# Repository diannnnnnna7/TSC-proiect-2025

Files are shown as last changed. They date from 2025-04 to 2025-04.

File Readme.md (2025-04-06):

E-Book Reader cu e-Paper si ESP32-C6

DeskAssistant este un dispozitiv portabil de tip E-Book Reader, construit in jurul microcontrolerului ESP32-C6, cu consum redus de energie si capabilitati de conectivitate Wi-Fi. Dispozitivul utilizeaza un display e-paper pentru citirea confortabila a cartilor, fiind alimentat de la o baterie Li-Po si gandit sa functioneze autonom timp indelungat.

Componente principale:

ESP32-C6 – Microcontroler principal cu Wi-Fi, SPI si I2C

E-Paper Display – Afisaj principal, ideal pentru citirea fara oboseala a ochilor

Memorie Flash NOR 64MB – Spatiu generos pentru carti, configurari sau fisiere

Senzor ambiental BME688 – Masoara temperatura, presiunea, umiditatea si calitatea aerului

RTC DS3231 – Ceas de timp real cu precizie ridicata si consum scazut

SD Card Slot – Optiune de stocare suplimentara pentru fisiere EPUB/PDF

Fuel Gauge MAX17048 – Monitorizeaza in timp real nivelul bateriei

LDO Regulator – Asigura tensiunea de 3.3V stabila pentru toate componentele

Conector USB-C – Incarcare si comunicatie UART pentru debugging

Dispozitivul se alimenteaza de la o baterie Li-Po si poate fi incarcat prin portul USB-C, avand un circuit de incarcare dedicat (MCP73831).

Interfete de comunicatie:

SPI – Utilizat pentru E-Paper, memorie Flash si card SD

I2C – Utilizat pentru senzorul BME688, RTC si Fuel Gauge

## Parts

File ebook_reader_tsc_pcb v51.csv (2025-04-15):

Qty | Value | Device | Package | Parts | Description | ARROW_PART_NUMBER | ARROW_PRICE-STOCK | AVAILABILITY | CENTROID_NOT_SPECIFIED | CHECK_PRICES | COPYRIGHT | DATASHEET | DESCRIPTION | DIGIKEY_DESCRIPTION | DIGIKEY_PART_NUMBER | HEIGHT | LEAD_FREE | MANUFACTURER_NAME | MANUFACTURER_PART_NUMBER | MF | MFR_NAME | MOUSER_PART_NUMBER | MOUSER_PRICE-STOCK | MOUSER_TESTING_PART_NUMBER | MOUSER_TESTING_PRICE-STOCK | MP | MPN | PACKAGE | POPULARITY | PREFIX | PRICE | PROD_ID | PURCHASE-URL | ROHS | SNAPEDA_LINK | SPICEMODEL | SPICEPREFIX | TEMPERATURE_RANGE_HIGH | TEMPERATURE_RANGE_LOW | TP_SIGNAL_NAME | VALUE
1 |  | ADAFRUIT_LEDCHIP-LED0603 | ADAFRUIT_CHIP-LED0603 | CHG_LED | LED
1 |  | SJ | SJ | SJ1 | SMD solder JUMPER |  |  |  |  |  |  |  |  |  |  |  |  |  |  |  |  |  |  |  |  |  |  |  | 3
1 | 0.47 | ESP32_WROVER_EAGLE-LTSPICE_RR0402 | ESP32_WROVER_EAGLE-LTSPICE_R0402 | R3 | RESISTOR, European symbol |  |  |  |  |  |  |  |  |  |  |  |  |  |  |  |  |  |  |  |  |  |  |  |  |  |  |  |  |  |  | NONE | R
1 | 100k | ESP32_WROVER_EAGLE-LTSPICE_RR0402 | ESP32_WROVER_EAGLE-LTSPICE_R0402 | R1_PWRUSB | RESISTOR, European symbol |  |  |  |  |  |  |  |  |  |  |  |  |  |  |  |  |  |  |  |  |  |  |  |  |  |  |  |  |  |  | NONE | R
8 | 100nF | ESP32_WROVER_EAGLE-LTSPICE_CC0402 | ESP32_WROVER_EAGLE-LTSPICE_C0402 | C1, C2, C4_USB, C6, C8, C9, C10, C_DELAY | CAPACITOR, European symbol |  |  |  |  |  |  |  |  |  |  |  |  |  |  |  |  |  |  |  |  |  |  |  |  |  |  |  |  |  |  | NONE | C
1 | 100uF | RCL_CPOL-EUCT3528 | RCL_CT3528 | C3 | POLARIZED CAPACITOR, European symbol |  |  |  |  |  |  |  |  |  |  |  |  |  |  |  |  |  |  |  |  |  |  |  | 0 |  |  |  |  |  |  |  | C
16 | 10K | ESP32_WROVER_EAGLE-LTSPICE_RR0402 | ESP32_WROVER_EAGLE-LTSPICE_R0402 | R1, R1_PINH, R1_PINH1, R2-PINH, R2_PINH1, R4, R5, R6, R7, R8, R9, R10, R_BOOT, R_CHANGE, R_CL1, R_RESET | RESISTOR, European symbol |  |  |  |  |  |  |  |  |  |  |  |  |  |  |  |  |  |  |  |  |  |  |  |  |  |  |  |  |  |  | NONE | R
1 | 10uF | ESP32_WROVER_EAGLE-LTSPICE_CC0402 | ESP32_WROVER_EAGLE-LTSPICE_C0402 | C7 | CAPACITOR, European symbol |  |  |  |  |  |  |  |  |  |  |  |  |  |  |  |  |  |  |  |  |  |  |  |  |  |  |  |  |  |  | NONE | C
1 | 112A-TAAR-R03_ATTEND | 112A-TAAR-R03_ATTEND | 112ATAARR03ATTEND | J4 | Micro SD Card Socket, Push-Push Type, Top Mount, SMT, H=1.83mm, 10u |  |  |  |  |  |  |  | Micro SD Card Socket | Push-Push Type | Top Mount | SMT | H=1.83mm | 10u |  |  | 1.9mm |  | ATTEND | 112A-TAAR-R03 ATTEND
1 | 15 | ESP32_WROVER_EAGLE-LTSPICE_RR0402 | ESP32_WROVER_EAGLE-LTSPICE_R0402 | R_CAPACITOR | RESISTOR, European symbol |  |  |  |  |  |  |  |  |  |  |  |  |  |  |  |  |  |  |  |  |  |  |  |  |  |  |  |  |  |  | NONE | R
1 | 1uF | ESP32_WROVER_EAGLE-LTSPICE_CC0402 | ESP32_WROVER_EAGLE-LTSPICE_C0402 | C5 | CAPACITOR, European symbol |  |  |  |  |  |  |  |  |  |  |  |  |  |  |  |  |  |  |  |  |  |  |  |  |  |  |  |  |  |  | NONE | C
10 | 1uF/50V | ESP32_WROVER_EAGLE-LTSPICE_CC0402 | ESP32_WROVER_EAGLE-LTSPICE_C0402 | EPD_C1, EPD_C2, EPD_C5, EPD_C6, EPD_C7, EPD_C8, EPD_C9, EPD_C10, EPD_C11, EPD_C12 | CAPACITOR, European symbol |  |  |  |  |  |  |  |  |  |  |  |  |  |  |  |  |  |  |  |  |  |  |  |  |  |  |  |  |  |  | NONE | C
1 | 2.2 | ESP32_WROVER_EAGLE-LTSPICE_RR0402 | ESP32_WROVER_EAGLE-LTSPICE_R0402 | R2 | RESISTOR, European symbol |  |  |  |  |  |  |  |  |  |  |  |  |  |  |  |  |  |  |  |  |  |  |  |  |  |  |  |  |  |  | NONE | R
1 | 200 | ESP32_WROVER_EAGLE-LTSPICE_RR0402 | ESP32_WROVER_EAGLE-LTSPICE_R0402 | R1_BAT | RESISTOR, European symbol |  |  |  |  |  |  |  |  |  |  |  |  |  |  |  |  |  |  |  |  |  |  |  |  |  |  |  |  |  |  | NONE | R
2 | 20V/4.2A/52m?/1.4W | ESP32_WROVER_SPARKFUN-DISCRETESEMI_MOSFET_PCH-DMG2305UX-7 | ESP32_WROVER_SPARKFUN-DISCRETESEMI_SOT23-3 | Q1, Q2 | P-channel MOSFETs |  |  |  |  |  |  |  |  |  |  |  |  |  |  |  |  |  |  |  |  |  |  |  |  |  |  | TRAN-14388 |  |  |  |  |  |  |  |  | 20V/4.2A/52m?/1.4W
1 | 2K | ESP32_WROVER_EAGLE-LTSPICE_RR0402 | ESP32_WROVER_EAGLE-LTSPICE_R0402 | R2_BAT | RESISTOR, European symbol |  |  |  |  |  |  |  |  |  |  |  |  |  |  |  |  |  |  |  |  |  |  |  |  |  |  |  |  |  |  | NONE | R
5 | 4.7uF | ESP32_WROVER_EAGLE-LTSPICE_CC0402 | ESP32_WROVER_EAGLE-LTSPICE_C0402 | C1_BAT, C1_BAT1, C1_BAT2, C2_BAT, C5_USB | CAPACITOR, European symbol |  |  |  |  |  |  |  |  |  |  |  |  |  |  |  |  |  |  |  |  |  |  |  |  |  |  |  |  |  |  | NONE | C
1 | 4.7uF/25V | ESP32_WROVER_EAGLE-LTSPICE_CC0402 | ESP32_WROVER_EAGLE-LTSPICE_C0402 | C4 | CAPACITOR, European symbol |  |  |  |  |  |  |  |  |  |  |  |  |  |  |  |  |  |  |  |  |  |  |  |  |  |  |  |  |  |  | NONE | C
2 | 5k1 | ESP32_WROVER_EAGLE-LTSPICE_RR0402 | ESP32_WROVER_EAGLE-LTSPICE_R0402 | R2-USB, R2-USB1 | RESISTOR, European symbol |  |  |  |  |  |  |  |  |  |  |  |  |  |  |  |  |  |  |  |  |  |  |  |  |  |  |  |  |  |  | NONE | R
1 | 68uH | 744043680IND_4828-WE-TPC_WRE | IND_4828-WE-TPC_WRE | L1 |  |  |  |  |  |  | Copyright (C) 2024 Ultra Librarian. All rights reserved. |  |  |  |  |  |  |  | 744043680 |  | Wurth Electronics
1 | BD5229G-TR | BD5229G-TR | SOT95P280X125-5N | IC1 | Voltage Detector with Adjustable Delay Time: CMOS processes are utilized to develop high precision, low current consumption CMOS reset ICs that allow arbitrary setting of the delay time. The extensive lineup includes both Nch Open Drain and CMOS output types in a wide range of detection voltages (from 2.3V to 6.0V, in 0.1V steps), enabling selection of the ideal solution based on customer requirements. In addition, the entire series is of course both lead-free and RoHS-compliant. |  |  |  |  |  |  |  | Voltage Detector with Adjustable Delay Time: CMOS processes are utilized to develop high precision | low current consumption CMOS reset ICs that allow arbitrary setting of the delay time. The extensive lineup includes both Nch Open Drain and CMOS output types in a wide range of detection voltages (from 2.3V to 6.0V | in 0.1V steps) | enabling selection of the ideal solution based on customer requirements. In addition | the entire series is of course both lead-free and RoHS-compliant. |  |  | 1.25mm |  | ROHM Semiconductor | BD5229G-TR |  |  | 755-BD5229G-TR | https://www.mouser.co.uk/ProductDetail/ROHM-Semiconductor/BD5229G-TR?qs=4kLU8WoGk0vvnhrrYwdszw%3D%3D
3 | BUTTON_CUSYOMV1 | BUTTON_CUSYOMV1 | MYBUTTON | BOOT_BUTTON, CHANGE_BUTTON, RESET_BUTTON
1 | CPH3225A | CPH3225A | CAPCP3225X100N | C10_SUPERCAP | Cap 0.011F 3.3V 1210 Flat Check availability |  |  | Not in stock |  | https://www.snapeda.com/parts/CPH3225A/Seiko+Instruments/view-part/?ref=eda |  |  | 11 mF (EDLC) Supercapacitor 3.3 V 1210 (3225 Metric) - - |  |  |  |  |  |  | Seiko Instruments |  |  |  |  |  | CPH3225A |  | 1210 Seiko |  |  | None |  | https://www.snapeda.com/api/url_track_click_mouser/?unipart_id=562593&manufacturer=Seiko Instruments&part_name=CPH3225A&search_term=None |  | https://www.snapeda.com/parts/CPH3225A/Seiko+Instruments/view-part/?ref=snap
1 | DS3231SN# | DS3231SN# | SOIC127P1032X265-16N | U3 | Real Time Clock Serial 16-Pin SOIC W T/R Check availability |  |  | In Stock |  | https://www.snapeda.com/parts/DS3231SN%23/Analog+Devices/view-part/?ref=eda |  |  | Extremely Accurate I2C-Integrated RTC/TCXO/Crystal |  |  |  |  |  |  | Analog Devices |  |  |  |  |  | DS3231SN# |  | SOIC-16 Maxim |  |  | None |  | https://www.snapeda.com/api/url_track_click_mouser/?unipart_id=99048&manufacturer=Analog Devices&part_name=DS3231SN#&search_term=None |  | https://www.snapeda.com/parts/DS3231SN%23/Analog+Devices/view-part/?ref=snap
1 | ESP32-C6-WROOM-1-N8 | ESP32-C6-WROOM-1-N8 | XCVR_ESP32-C6-WROOM-1-N8 | U2 | Check availability |  |  | In Stock |  | https://www.snapeda.com/parts/ESP32-C6-WROOM-1-N8/Espressif+Systems/view-part/?ref=eda |  |  | Multiprotocol Modules ESP32-C6 module | Wi-Fi 6 in 2.4 GHz band | Bluetooth 5 | Zigbee 3.0 and Thread. ESP34-WROOM Compatible - ENGINEERING SAMPLE |  |  |  |  |  |  | Espressif Systems |  |  |  |  |  | ESP32-C6-WROOM-1-N8 |  | None |  |  | None |  |  |  | https://www.snapeda.com/parts/ESP32-C6-WROOM-1-N8/Espressif+Systems/view-part/?ref=snap
1 | ESP32C6_VARISTORCN1812 | ESP32C6_VARISTORCN1812 | ESP32C6_VARISTOR_CT/CN1812 | PFMF.050.1 | VARISTOR |  |  |  |  |  |  |  |  |  |  |  |  |  |  |  |  |  |  |  |  |  |  |  | 0
2 | ESP32_WROVER_AVX---SD0805S020S1R0_AVX_SD0805S020S1R0_0_0AVX_SD0805S020S1R0_0_0 | ESP32_WROVER_AVX---SD0805S020S1R0_AVX_SD0805S020S1R0_0_0AVX_SD0805S020S1R0_0_0 | ESP32_WROVER_AVX---SD0805S020S1R0_AVX_SD0805S020S1R0_0 | D2, D7 | Schottky Barrier Rectifier Diode |  |  |  | No |  |  | http://datasheets.avx.com/schottky.pdf |  | DIODE SCHOTTKY 20V 1A 0805 | 478-7800-1-ND |  | yes |  |  | AVX |  | 581-SD0805S020S1R0 |  |  |  |  |  | 0805 (2012 metric) |  | D |  |  |  | yes |  |  |  | +125°C | -55°C
1 | ESP32_WROVER_BME680_BME680 | ESP32_WROVER_BME680_BME680 | ESP32_WROVER_BME680_PSON80P300X300X100-8N | SENSOR2 | Integrated Environmental Unit |  |  | Unavailable |  |  |  |  | Integrated Environmental Unit |  |  |  |  |  |  | Bosch Sensortec |  |  |  |  |  | BME680 |  | LGA-8 Bosch Tools |  |  | None
1 | ESP32_WROVER_SPARKFUN-IC-POWER_MCP73831 | ESP32_WROVER_SPARKFUN-IC-POWER_MCP73831 | ESP32_WROVER_SPARKFUN-IC-POWER_SOT23-5 | MCP73831 | MCP73831T Li-Ion, Li-Pol Controller |  |  |  |  |  |  |  |  |  |  |  |  |  |  |  |  |  |  |  |  |  |  |  |  |  |  | IC-09995
1 | FH34SRJ-24S-0.5SH_99_ | FH34SRJ-24S-0.5SH_99_ | FH34SRJ24S05SH99 | J1 | (0.50mm) Surface Mount, Right Angle |  |  |  |  |  |  |  | 24 Position FFC | FPC Connector Contacts | (0.50mm) Surface Mount | Right Angle |  |  | 1.1mm |  | Hirose | FH34SRJ-24S-0.5SH(99) |  |  | 798-FH34SRJ24S05SH99 | https://www.mouser.co.uk/ProductDetail/Hirose-Connector/FH34SRJ-24S-0.5SH99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
1 | MAX17048G+T10 | MAX17048G+T10 | SON50P200X200X80-9N | U4 | Check availability |  |  | In Stock |  | https://www.snapeda.com/parts/MAX17048G+T10/Analog+Devices/view-part/?ref=eda |  |  | 3µA 1-Cell/2-Cell Fuel Gauge with ModelGauge |  |  |  |  |  |  | Analog Devices |  |  |  |  |  | MAX17048G+T10 |  | TDFN-8 Maxim |  |  | None |  | https://www.snapeda.com/api/url_track_click_mouser/?unipart_id=329239&manufacturer=Analog Devices&part_name=MAX17048G+T10&search_term=None |  | https://www.snapeda.com/parts/MAX17048G+T10/Analog+Devices/view-part/?ref=snap
3 | MBR0530 | MBR0530 | SOD3716X135N | D3, D4, D5 | ON SEMICONDUCTOR - MBR0530 - DIODE, SCHOTTKY, 0.5A, 30V, SOD-123 |  |  | In Stock |  | https://www.snapeda.com/parts/MBR0530/Onsemi/view-part/?ref=eda |  |  | Diode Schottky 30 V 500mA Surface Mount SOD-123 |  |  |  |  |  |  | ON Semiconductor |  |  |  |  |  | MBR0530 |  | SOD-123-2 ON Semiconductor |  |  | None |  | https://www.snapeda.com/api/url_track_click_mouser/?unipart_id=179458&manufacturer=ON Semiconductor&part_name=MBR0530&search_term=None |  | https://www.snapeda.com/parts/MBR0530/Onsemi/view-part/?ref=snap
6 | PGB1010603MR | PGB1010603MR | DIOC1608X36N | D6, D8, D9, D10, D11, D12 | Check availability |  |  | In Stock |  | https://www.snapeda.com/parts/PGB1010603MR/Littelfuse/view-part/?ref=eda |  |  | 150V (Typ) Clamp - Ipp Tvs Diode Surface Mount 0603 (1608 Metric) |  |  |  |  |  |  | Littelfuse Inc. |  |  |  |  |  | PGB1010603MR |  | 0603 Littelfuse Inc. |  |  | None |  | https://www.snapeda.com/api/url_track_click_mouser/?unipart_id=5659453&manufacturer=Littelfuse Inc.&part_name=PGB1010603MR&search_term=None |  | https://www.snapeda.com/parts/PGB1010603MR/Littelfuse/view-part/?ref=snap
1 | QWIIC_RIGHT_ANGLE | QWIIC_CONNECTORJS-1MM | JST04_1MM_RA | J3 | SparkFun I2C Standard Qwiic Connector |  |  |  |  |  |  |  |  |  |  |  |  |  |  |  |  |  |  |  |  |  |  |  |  |  |  | CONN-13694 |  |  |  |  |  |  |  |  | QWIIC_RIGHT_ANGLE
1 | SAMACSYS_PARTS_USB4110-GF-A | SAMACSYS_PARTS_USB4110-GF-A | SAMACSYS_PARTS_USB4110GFA | J2 | CONN USB 2.0 TYPE-C R/A SMT |  |  |  |  |  |  |  | CONN USB 2.0 TYPE-C R/A SMT |  |  | 3.26mm |  | GCT (GLOBAL CONNECTOR TECHNOLOGY) | USB4110-GF-A |  |  | 640-USB4110-GF-A | https://www.mouser.co.uk/ProductDetail/GCT/USB4110-GF-A?qs=KUoIvG%2F9IlYiZvIXQjyJeA%3D%3D
1 | SI1308EDL-T1-GE3 | SI1308EDL-T1-GE3 | SOT65P210X110-3N | Q3 | MOSFET N-Ch 30V 1.5A TrenchFET SC70 Vishay Si1308EDL-T1-GE3 N-channel MOSFET Transistor, 1.5 A, 30 V, 3-Pin SC-70 |  |  | In Stock |  | https://www.snapeda.com/parts/SI1308EDL-T1-GE3/Vishay+Siliconix/view-part/?ref=eda |  |  | Si1308EDL-T1-GE3 N-channel MOSFET Transistor | 1.5 A | 30 V | 3-Pin SC-70 | Siliconix / Vishay SI1308EDL-T1-GE3 |  |  |  |  |  |  | Vishay Siliconix |  |  |  |  |  | SI1308EDL-T1-GE3 |  | SOT-323 Vishay Semiconductor |  |  | None |  | https://www.snapeda.com/api/url_track_click_mouser/?unipart_id=274603&manufacturer=Vishay Siliconix&part_name=SI1308EDL-T1-GE3&search_term=None |  | https://www.snapeda.com/parts/SI1308EDL-T1-GE3/Vishay+Siliconix/view-part/?ref=snap
17 | TPTP20R | TPTP20R | TP20R | TP1, TP2, TP3, TP4, TP5, TP6, TP7, TP8, TP9, TP10, TP11, TP12, TP13, TP14, TP15, TP16, TP17 | Test pad |  |  |  |  |  |  |  |  |  |  |  |  |  |  |  |  |  |  |  |  |  |  |  | 2
1 | USBLC6-2SC6Y | USBLC6-2SC6Y | SOT95P280X145-6N | D1 | Low Cap. ESD Protection Auto SOT-23-6 STMicroelectronics USBLC6-2SC6Y, Dual Uni-Directional TVS Diode Array, 6-Pin SOT-23 |  |  | In Stock |  | https://www.snapeda.com/parts/USBLC6-2SC6Y/STMicroelectronics/view-part/?ref=eda |  |  | 17V Clamp 5A (8/20µs) Ipp Tvs Diode Surface Mount SOT-23-6 |  |  |  |  |  |  | STMicroelectronics |  |  |  |  |  | USBLC6-2SC6Y |  | SOT-23-6 STMicroelectronics |  |  | None |  |  |  | https://www.snapeda.com/parts/USBLC6-2SC6Y/STMicroelectronics/view-part/?ref=snap
1 | W25Q512JVEIQ | W25Q512JVEIQ | SON127P600X800X80-9N | U1 | Check availability |  |  | In Stock |  | https://www.snapeda.com/parts/W25Q512JVEIQ/Winbond+Electronics/view-part/?ref=eda |  |  | FLASH - NOR Memory IC 512Mb (64M x 8) SPI - Quad I/O 133 MHz 8-WSON (8x6) |  |  |  |  |  |  | Winbond Electronics |  |  |  |  |  | W25Q512JVEIQ |  | Package |  |  | None |  |  |  | https://www.snapeda.com/parts/W25Q512JVEIQ/Winbond+Electronics/view-part/?ref=snap
1 | XC6220A331MR-G | XC6220A331MR-G | SOT95P280X120-5N | IC4 | LDO Voltage Regulators |  |  |  |  |  |  |  | LDO Voltage Regulators |  |  | 1.2mm |  | Torex | XC6220A331MR-G |  |  | 865-XC6220A331MR-G | https://www.mouser.co.uk/ProductDetail/Torex-Semiconductor/XC6220A331MR-G?qs=AsjdqWjXhJ8ZSWznL1J0gg%3D%3D

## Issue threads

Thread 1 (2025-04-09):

[ERC] GND conectat la două neturi diferite (GND și PREVGL)

darimari21, 2025-04-09:
Locatie:Header-ul e-paper display
In urma ruralii ERC-ului s-a constatat o eroare de tipul : SUPPLY pin GND overwritten with more than one signal (GND, PREVGL)

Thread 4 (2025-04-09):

Issue: Componente fără valoare specificată (SJ1, R5–R10, CHG_LED, FRAME1)

darimari21, 2025-04-09:
Mai multe componente din schematic nu au completată valoarea (has no value)

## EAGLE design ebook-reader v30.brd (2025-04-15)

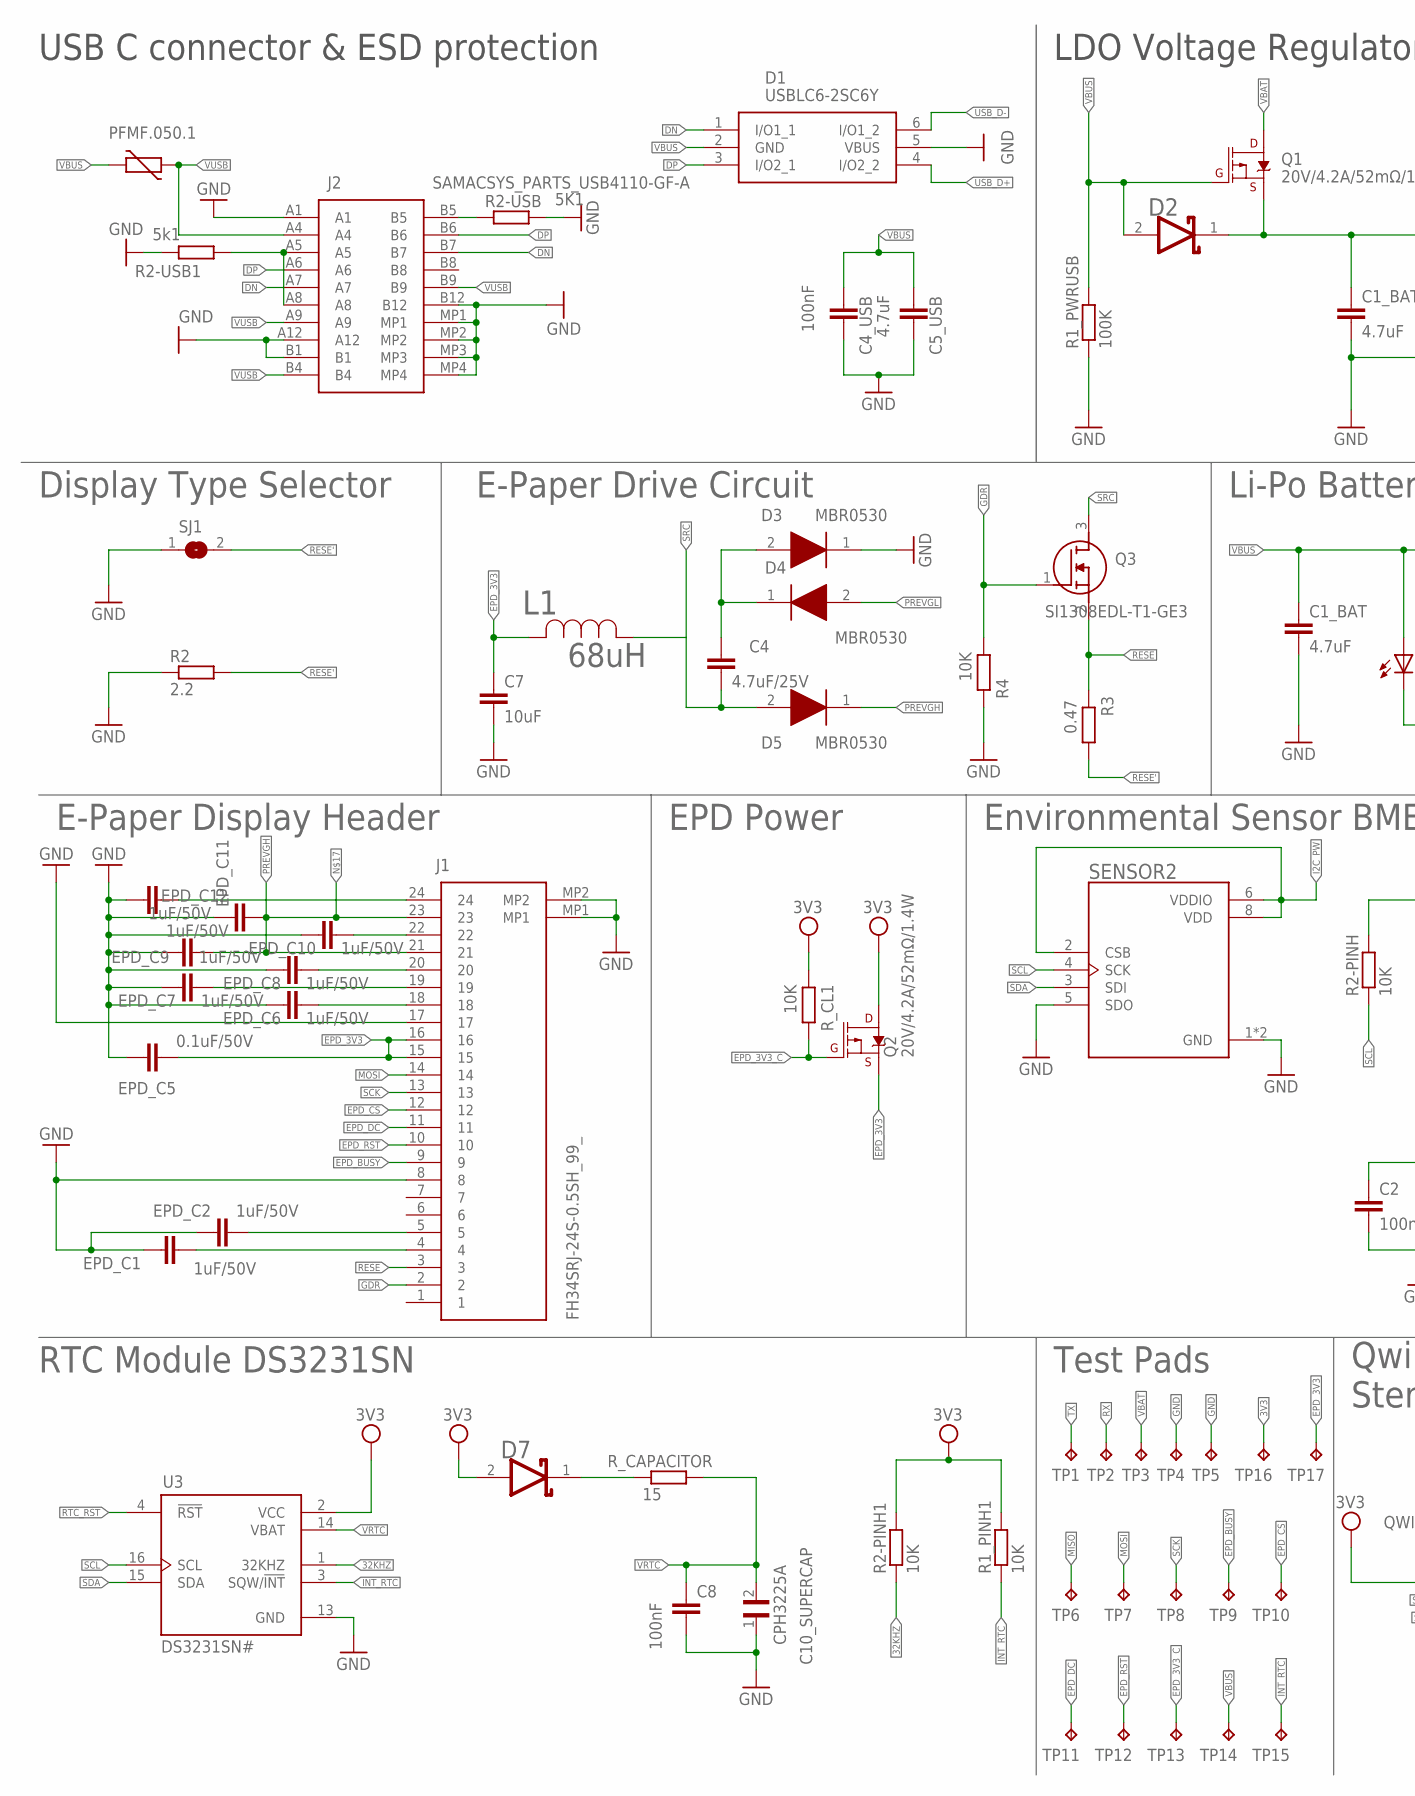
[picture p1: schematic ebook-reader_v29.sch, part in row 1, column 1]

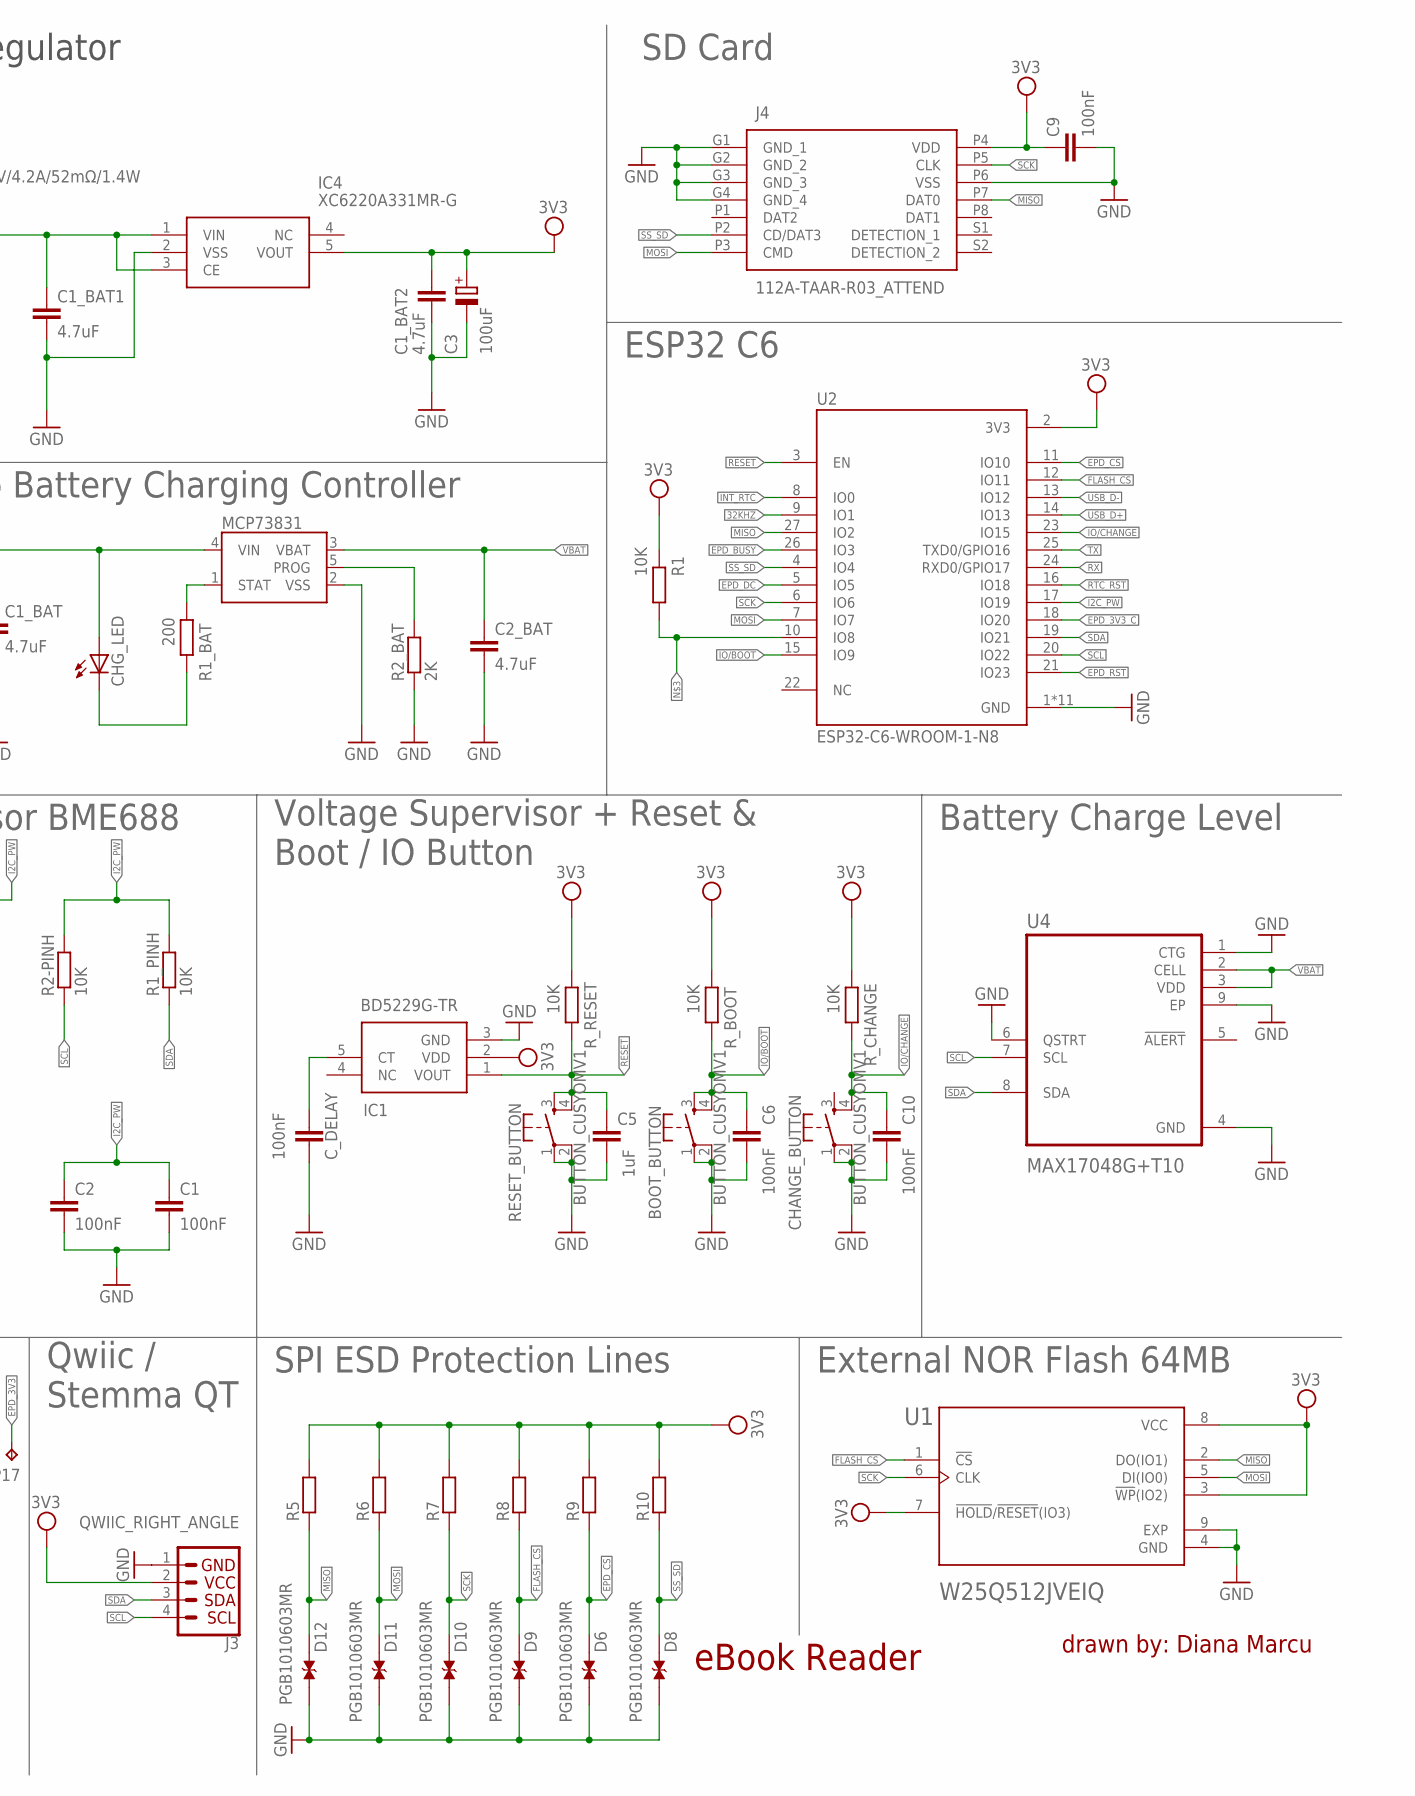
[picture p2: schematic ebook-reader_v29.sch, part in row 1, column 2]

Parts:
BOOT_BUTTON: BUTTON_CUSYOMV1; MYBUTTON
C1, C2, C4_USB, C6, C8, C9, C10: 100nF; EAGLE-LTSPICE_C0402
C1_BAT, C1_BAT1, C1_BAT2, C2_BAT, C5_USB: 4.7uF; EAGLE-LTSPICE_C0402
C3: 100uF; RCL_CT3528
C4: 4.7uF/25V; EAGLE-LTSPICE_C0402
C5: 1uF; EAGLE-LTSPICE_C0402
C7: 10uF; EAGLE-LTSPICE_C0402
C10_SUPERCAP: CPH3225A; CAPCP3225X100N
CHANGE_BUTTON: BUTTON_CUSYOMV1; MYBUTTON
CHG_LED: ADAFRUIT_LEDCHIP-LED0603; ADAFRUIT_CHIP-LED0603
C_DELAY: 100nF; EAGLE-LTSPICE_C0402
D1: USBLC6-2SC6Y; SOT95P280X145-6N
D2, D7: ESP32_WROVER_AVX---SD0805S020S1R0_AVX_SD0805S020S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; ESP32_WROVER_AVX---SD0805S020S1R0_AVX_SD0805S020S1R0_0
D3, D4, D5: MBR0530; SOD3716X135N
D6, D8, D9, D10, D11, D12: PGB1010603MR; DIOC1608X36N
EPD_C1, EPD_C2, EPD_C6, EPD_C7, EPD_C8, EPD_C9, EPD_C10, EPD_C11, EPD_C12: 1uF/50V; EAGLE-LTSPICE_C0402
EPD_C5: 0.1uF/50V; EAGLE-LTSPICE_C0402
IC1: BD5229G-TR; SOT95P280X125-5N
IC4: XC6220A331MR-G; SOT95P280X120-5N
J1: FH34SRJ-24S-0.5SH_99_; FH34SRJ24S05SH99
J2: SAMACSYS_PARTS_USB4110-GF-A; SAMACSYS_PARTS_USB4110GFA
J3: QWIIC_RIGHT_ANGLE; JST04_1MM_RA
J4: 112A-TAAR-R03_ATTEND; 112ATAARR03ATTEND
L1: 68uH; IND_4828-WE-TPC_WRE
MCP73831: ESP32_WROVER_SPARKFUN-IC-POWER_MCP73831; ESP32_WROVER_SPARKFUN-IC-POWER_SOT23-5
PFMF.050.1: ESP32C6_VARISTORCN1812; ESP32C6_VARISTOR_CT/CN1812
Q1, Q2: 20V/4.2A/52mΩ/1.4W; ESP32_WROVER_SPARKFUN-DISCRETESEMI_SOT23-3
Q3: SI1308EDL-T1-GE3; SOT65P210X110-3N
R1, R1_PINH, R1_PINH1, R2-PINH, R2-PINH1, R4: 10K; ESP32_WROVER_EAGLE-LTSPICE_R0402
R1_BAT: 200; ESP32_WROVER_EAGLE-LTSPICE_R0402
R1_PWRUSB: 100K; ESP32_WROVER_EAGLE-LTSPICE_R0402
R2: 2.2; ESP32_WROVER_EAGLE-LTSPICE_R0402
R2-USB: 5K1; ESP32_WROVER_EAGLE-LTSPICE_R0402
R2-USB1: 5k1; ESP32_WROVER_EAGLE-LTSPICE_R0402
R2_BAT: 2K; ESP32_WROVER_EAGLE-LTSPICE_R0402
R3: 0.47; ESP32_WROVER_EAGLE-LTSPICE_R0402
R5, R6, R7, R8, R9, R10: ESP32_WROVER_EAGLE-LTSPICE_RR0402; ESP32_WROVER_EAGLE-LTSPICE_R0402
RESET_BUTTON: BUTTON_CUSYOMV1; MYBUTTON
R_BOOT: 10K; ESP32_WROVER_EAGLE-LTSPICE_R0402
R_CAPACITOR: 15; ESP32_WROVER_EAGLE-LTSPICE_R0402
R_CHANGE: 10K; ESP32_WROVER_EAGLE-LTSPICE_R0402
R_CL1: 10K; ESP32_WROVER_EAGLE-LTSPICE_R0402
R_RESET: 10K; ESP32_WROVER_EAGLE-LTSPICE_R0402
SENSOR2: ESP32_WROVER_BME680_BME680; ESP32_WROVER_BME680_PSON80P300X300X100-8N
SJ1: SJ
TP1, TP2, TP3, TP4, TP5, TP6, TP7, TP8, TP9, TP10, TP11, TP12, TP13, TP14, TP15, TP16, TP17: TPTP20R; TP20R
U1: W25Q512JVEIQ; SON127P600X800X80-9N
U2: ESP32-C6-WROOM-1-N8; XCVR_ESP32-C6-WROOM-1-N8
U3: DS3231SN#; SOIC127P1032X265-16N
U4: MAX17048G+T10; SON50P200X200X80-9N

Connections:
3V3: C1_BAT2.1, C3.+, C9.1, D7.2 (ANODE), IC1.2 (VDD), IC4.5 (VOUT), J3.2, J4.P4 (VDD), Q2.3 (D), R1.2, R1_PINH1.2, R2-PINH1.2, R5.2, R6.2, R7.2, R8.2, R9.2, R10.2, R_BOOT.2, R_CHANGE.2, R_CL1.2, R_RESET.2, TP16.TP, U1.3 (!WP!(IO2)), U1.7 (!HOLD!/!RESET!(IO3)), U1.8 (VCC), U2.2 (3V3), U3.2 (VCC)
32KHZ: R2-PINH1.1, U2.9 (IO1), U3.1 (32KHZ)
DN: D1.1 (I/O1_1), J2.A7, J2.B7
DP: D1.3 (I/O2_1), J2.A6, J2.B6
EPD_3V3: C7.1, EPD_C5.2, J1.15, J1.16, L1.2, Q2.2 (S), TP17.TP
EPD_3V3_C: Q2.1 (G), R_CL1.1, TP13.TP, U2.18 (IO20)
EPD_BUSY: J1.9, TP9.TP, U2.26 (IO3)
EPD_CS: D11.2, J1.12, R9.1, TP10.TP, U2.11 (IO10)
EPD_DC: J1.11, TP11.TP, U2.5 (IO5)
EPD_RST: J1.10, TP12.TP, U2.21 (IO23)
FLASH_CS: D10.2, R8.1, U1.1 (!CS), U2.12 (IO11)
GDR: J1.2, Q3.1 (G), R4.2
I2C_PW: C1.1, C2.1, R1_PINH.2, R2-PINH.2, SENSOR2.2 (CSB), SENSOR2.6 (VDDIO), SENSOR2.8 (VDD), U2.17 (IO19)
INT_RTC: R1_PINH1.1, TP15.TP, U2.8 (IO0), U3.3 (SQW/!INT)
IO/BOOT: BOOT_BUTTON.3, BOOT_BUTTON.4, C6.1, R_BOOT.1, U2.15 (IO9)
IO/CHANGE: C10.1, CHANGE_BUTTON.4, R_CHANGE.1, U2.23 (IO15)
MISO: D6.2, J4.P7 (DAT0), R5.1, TP6.TP, U1.2 (DO(IO1)), U2.27 (IO2)
MOSI: D9.2, J1.14, J4.P3 (CMD), R6.1, TP7.TP, U1.5 (DI(IO0)), U2.7 (IO7)
unnamed: J2.A5, J2.A8, R2-USB1.2
unnamed: J2.B5, R2-USB.1
unnamed: C1_BAT1.1, D2.1 (CATHODE), IC4.1 (VIN), IC4.3 (CE), Q1.2 (S)
unnamed: CHG_LED.C, R1_BAT.1
unnamed: C4.1, D3.2 (A), D4.1 (K)
unnamed: MCP73831.1 (STAT), R1_BAT.2
unnamed: MCP73831.5 (PROG), R2_BAT.2
unnamed: EPD_C1.2, J1.4
unnamed: EPD_C2.2, J1.5
unnamed: C_DELAY.1, IC1.5 (CT)
unnamed: D7.1 (CATHODE), R_CAPACITOR.1
unnamed: EPD_C12.2, J1.24
unnamed: EPD_C10.2, J1.22
unnamed: EPD_C9.1, EPD_C11.2, J1.21, J1.23
unnamed: EPD_C8.2, J1.20
unnamed: EPD_C7.2, J1.19
unnamed: EPD_C6.2, J1.18
PREVGH: D5.1 (K)
RESE: J1.3, Q3.2 (S), R3.2
RESE': R2.2, R3.1, SJ1.2
RESET: C5.1, IC1.1 (VOUT), RESET_BUTTON.3, RESET_BUTTON.4, R_RESET.1, U2.3 (EN)
RTC_RST: U2.16 (IO18), U3.4 (!RST)
RX: TP2.TP, U2.24 (RXD0/GPIO17)
SCK: D8.2, J1.13, J4.P5 (CLK), R7.1, TP8.TP, U1.6 (CLK), U2.6 (IO6)
SCL: J3.4, R2-PINH.1, SENSOR2.4 (SCK), U2.20 (IO22), U3.16 (SCL), U4.7 (SCL)
SDA: J3.3, R1_PINH.1, SENSOR2.3 (SDI), U2.19 (IO21), U3.15 (SDA), U4.8 (SDA)
SRC: C4.2, D5.2 (A), L1.1, Q3.3 (D)
SS_SD: D12.2, J4.P2 (CD/DAT3), R10.1, U2.4 (IO4)
TX: TP1.TP, U2.25 (TXD0/GPIO16)
USB_D+: D1.4 (I/O2_2), U2.14 (IO13)
USB_D-: D1.6 (I/O1_2), U2.13 (IO12)
VBAT: C2_BAT.1, D2.2 (ANODE), MCP73831.3 (VBAT), Q1.1 (G), R1_PWRUSB.2, TP3.TP, U4.2 (CELL), U4.3 (VDD)
VBUS: C1_BAT.1, C4_USB.1, C5_USB.1, CHG_LED.A, D1.2 (GND), MCP73831.4 (VIN), PFMF.050.1.2, TP14.TP
VRTC: C8.1, C10_SUPERCAP.2, R_CAPACITOR.2, U3.14 (VBAT)
VUSB: J2.A4, J2.A9, J2.B4, J2.B9, PFMF.050.1.1

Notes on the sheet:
USB C connector & ESD protection
LDO Voltage Regulator
SD Card
Display Type Selector
E-Paper Drive Circuit
Li-Po Battery Charging Controller
ESP32 C6
E-Paper Display Header
EPD Power
Environmental Sensor BME688
Voltage Supervisor + Reset & Boot / IO Button
Battery Charge Level
RTC Module DS3231SN
Test Pads
Qwiic / Stemma QT
SPI ESD Protection Lines
External NOR Flash 64MB
eBook Reader
drawn by: Diana Marcu

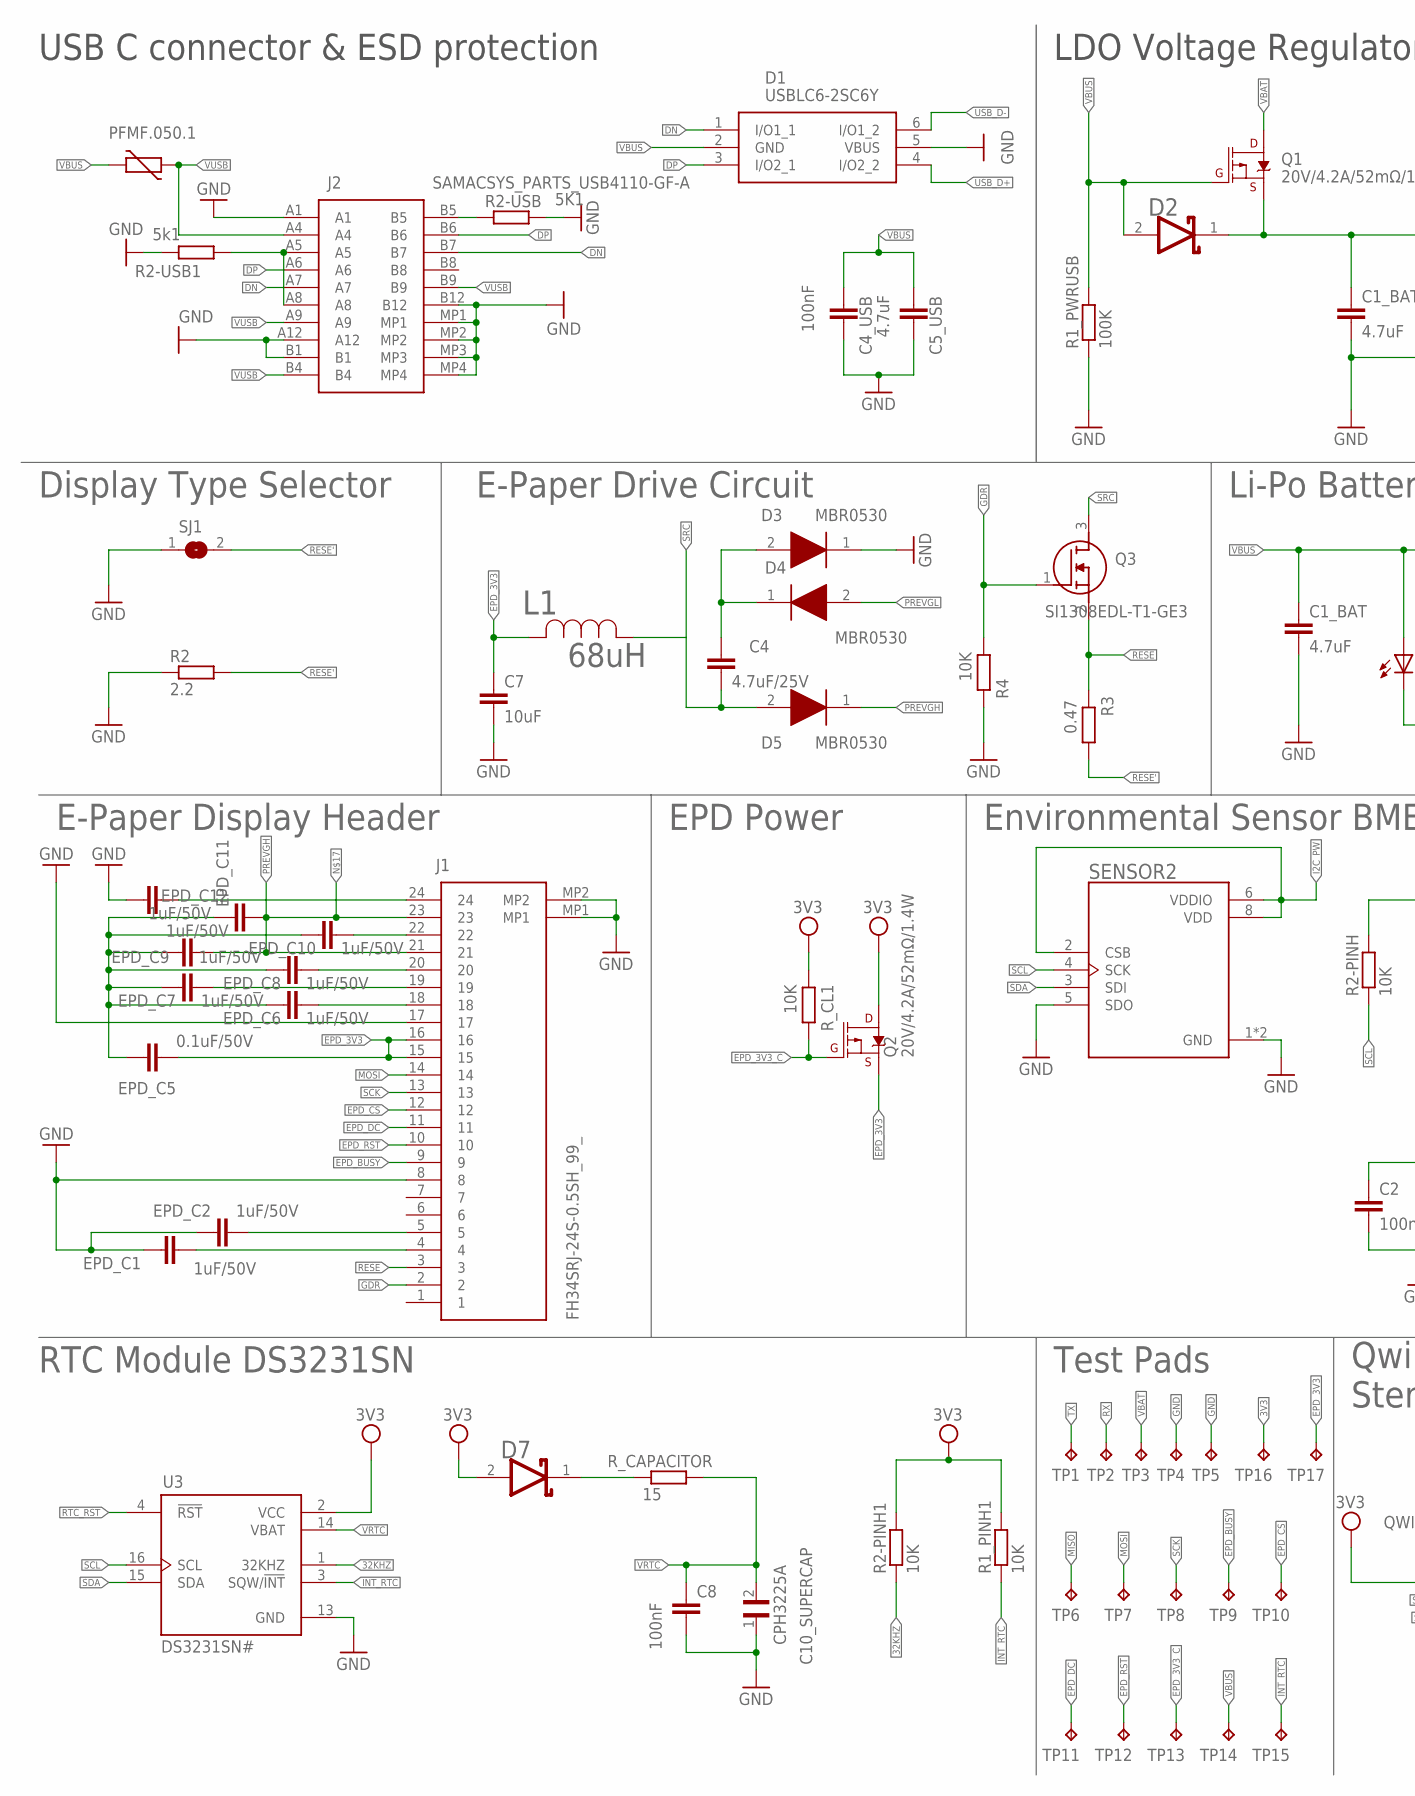
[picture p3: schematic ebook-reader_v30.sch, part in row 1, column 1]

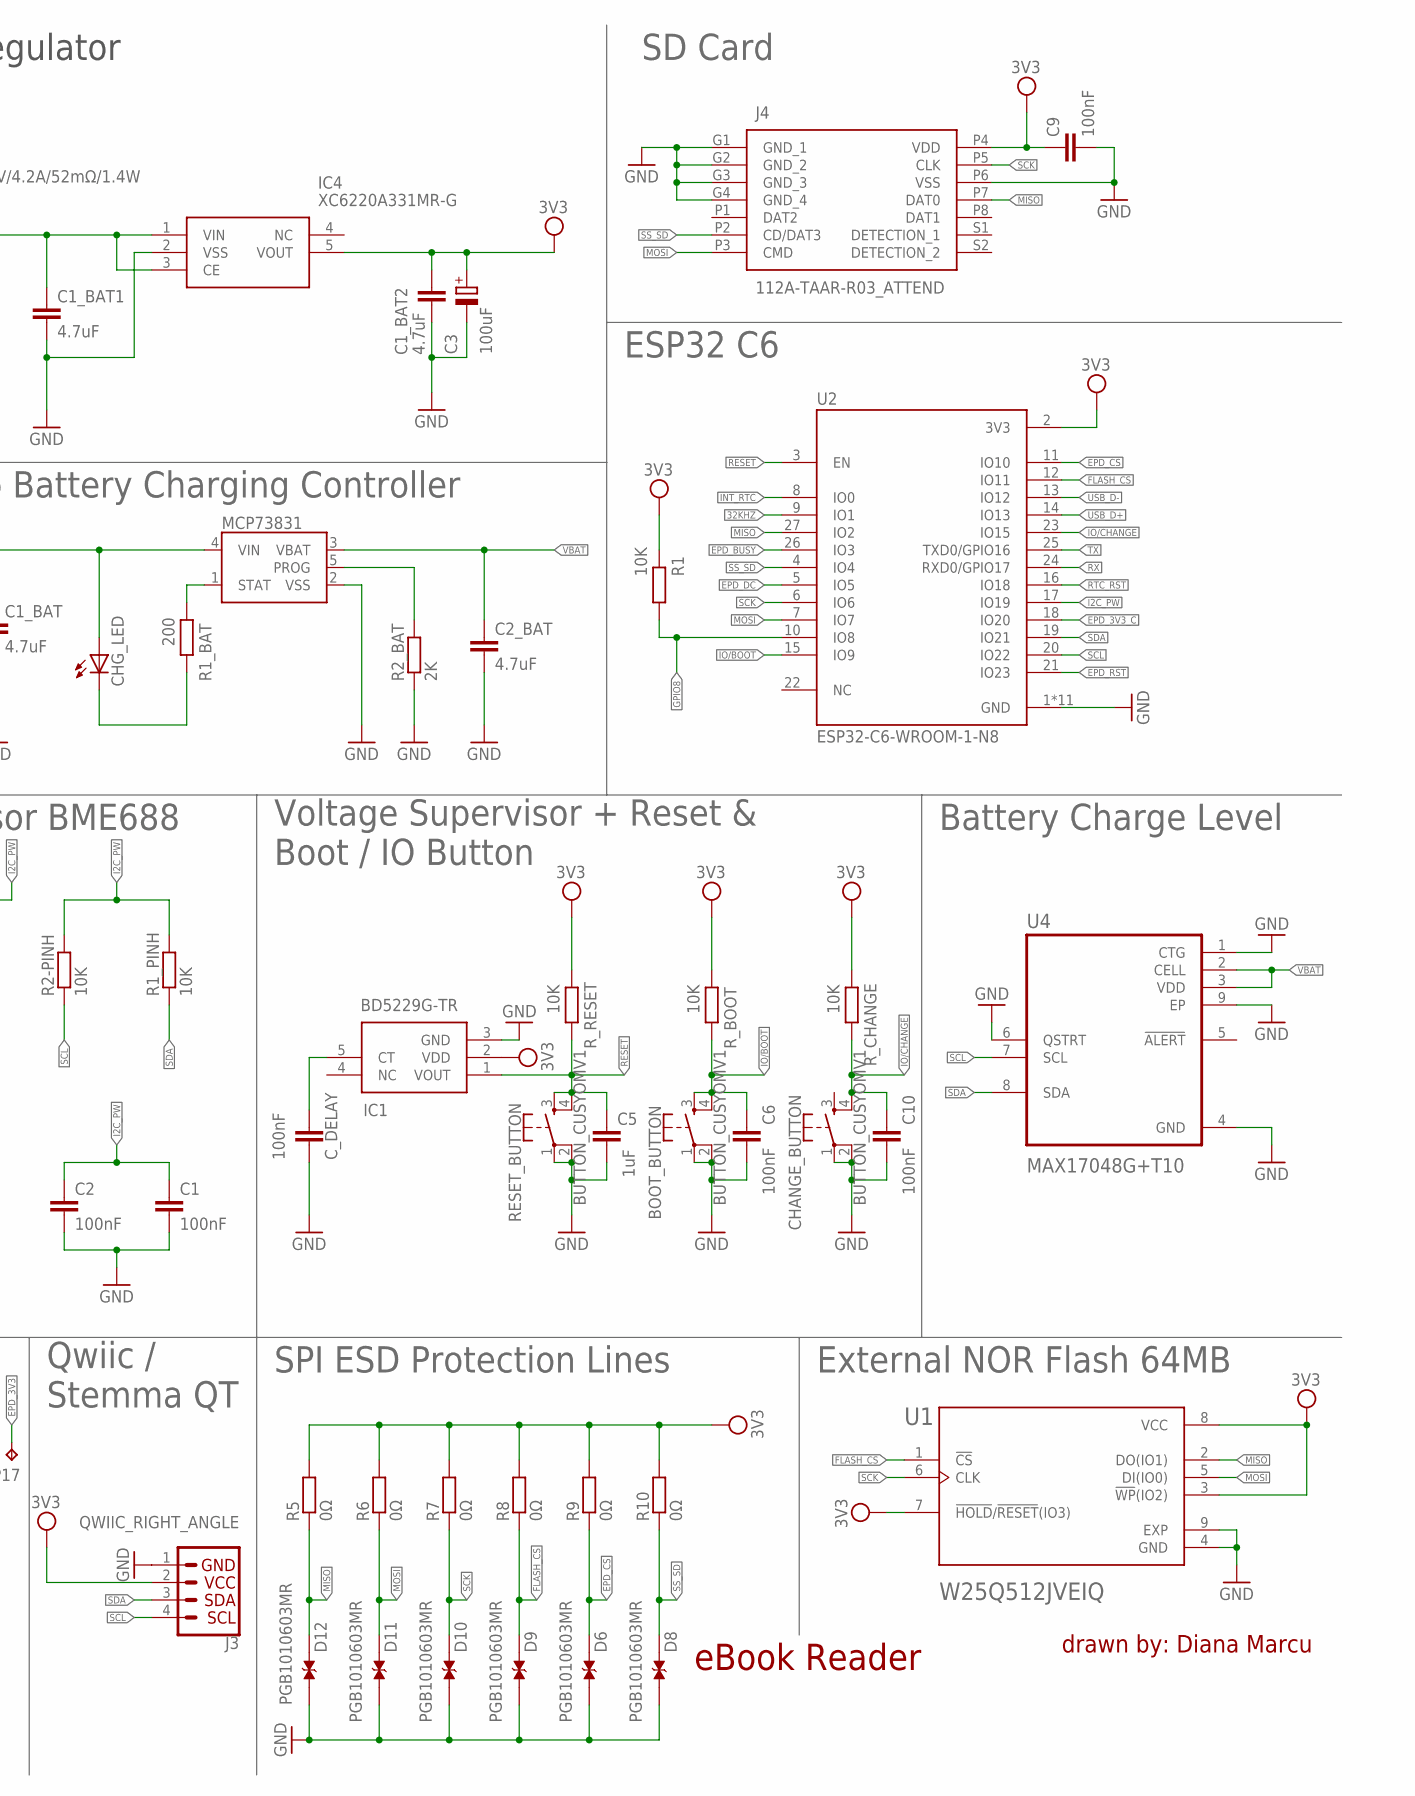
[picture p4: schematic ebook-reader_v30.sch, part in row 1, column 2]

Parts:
BOOT_BUTTON: BUTTON_CUSYOMV1; MYBUTTON
C1, C2, C4_USB, C6, C8, C9, C10: 100nF; EAGLE-LTSPICE_C0402
C1_BAT, C1_BAT1, C1_BAT2, C2_BAT, C5_USB: 4.7uF; EAGLE-LTSPICE_C0402
C3: 100uF; RCL_CT3528
C4: 4.7uF/25V; EAGLE-LTSPICE_C0402
C5: 1uF; EAGLE-LTSPICE_C0402
C7: 10uF; EAGLE-LTSPICE_C0402
C10_SUPERCAP: CPH3225A; CAPCP3225X100N
CHANGE_BUTTON: BUTTON_CUSYOMV1; MYBUTTON
CHG_LED: ADAFRUIT_LEDCHIP-LED0603; ADAFRUIT_CHIP-LED0603
C_DELAY: 100nF; EAGLE-LTSPICE_C0402
D1: USBLC6-2SC6Y; SOT95P280X145-6N
D2, D7: ESP32_WROVER_AVX---SD0805S020S1R0_AVX_SD0805S020S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; ESP32_WROVER_AVX---SD0805S020S1R0_AVX_SD0805S020S1R0_0
D3, D4, D5: MBR0530; SOD3716X135N
D6, D8, D9, D10, D11, D12: PGB1010603MR; DIOC1608X36N
EPD_C1, EPD_C2, EPD_C6, EPD_C7, EPD_C8, EPD_C9, EPD_C10, EPD_C11, EPD_C12: 1uF/50V; EAGLE-LTSPICE_C0402
EPD_C5: 0.1uF/50V; EAGLE-LTSPICE_C0402
IC1: BD5229G-TR; SOT95P280X125-5N
IC4: XC6220A331MR-G; SOT95P280X120-5N
J1: FH34SRJ-24S-0.5SH_99_; FH34SRJ24S05SH99
J2: SAMACSYS_PARTS_USB4110-GF-A; SAMACSYS_PARTS_USB4110GFA
J3: QWIIC_RIGHT_ANGLE; JST04_1MM_RA
J4: 112A-TAAR-R03_ATTEND; 112ATAARR03ATTEND
L1: 68uH; IND_4828-WE-TPC_WRE
MCP73831: ESP32_WROVER_SPARKFUN-IC-POWER_MCP73831; ESP32_WROVER_SPARKFUN-IC-POWER_SOT23-5
PFMF.050.1: ESP32C6_VARISTORCN1812; ESP32C6_VARISTOR_CT/CN1812
Q1, Q2: 20V/4.2A/52mΩ/1.4W; ESP32_WROVER_SPARKFUN-DISCRETESEMI_SOT23-3
Q3: SI1308EDL-T1-GE3; SOT65P210X110-3N
R1, R1_PINH, R1_PINH1, R2-PINH, R2-PINH1, R4: 10K; ESP32_WROVER_EAGLE-LTSPICE_R0402
R1_BAT: 200; ESP32_WROVER_EAGLE-LTSPICE_R0402
R1_PWRUSB: 100K; ESP32_WROVER_EAGLE-LTSPICE_R0402
R2: 2.2; ESP32_WROVER_EAGLE-LTSPICE_R0402
R2-USB: 5K1; ESP32_WROVER_EAGLE-LTSPICE_R0402
R2-USB1: 5k1; ESP32_WROVER_EAGLE-LTSPICE_R0402
R2_BAT: 2K; ESP32_WROVER_EAGLE-LTSPICE_R0402
R3: 0.47; ESP32_WROVER_EAGLE-LTSPICE_R0402
R5, R6, R7, R8, R9, R10: 0Ω; ESP32_WROVER_EAGLE-LTSPICE_R0402
RESET_BUTTON: BUTTON_CUSYOMV1; MYBUTTON
R_BOOT: 10K; ESP32_WROVER_EAGLE-LTSPICE_R0402
R_CAPACITOR: 15; ESP32_WROVER_EAGLE-LTSPICE_R0402
R_CHANGE: 10K; ESP32_WROVER_EAGLE-LTSPICE_R0402
R_CL1: 10K; ESP32_WROVER_EAGLE-LTSPICE_R0402
R_RESET: 10K; ESP32_WROVER_EAGLE-LTSPICE_R0402
SENSOR2: ESP32_WROVER_BME680_BME680; ESP32_WROVER_BME680_PSON80P300X300X100-8N
SJ1: SJ
TP1, TP2, TP3, TP4, TP5, TP6, TP7, TP8, TP9, TP10, TP11, TP12, TP13, TP14, TP15, TP16, TP17: TPTP20R; TP20R
U1: W25Q512JVEIQ; SON127P600X800X80-9N
U2: ESP32-C6-WROOM-1-N8; XCVR_ESP32-C6-WROOM-1-N8
U3: DS3231SN#; SOIC127P1032X265-16N
U4: MAX17048G+T10; SON50P200X200X80-9N

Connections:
3V3: C1_BAT2.1, C3.+, C9.1, D7.2 (ANODE), IC1.2 (VDD), IC4.5 (VOUT), J3.2, J4.P4 (VDD), Q2.3 (D), R1.2, R1_PINH1.2, R2-PINH1.2, R5.2, R6.2, R7.2, R8.2, R9.2, R10.2, R_BOOT.2, R_CHANGE.2, R_CL1.2, R_RESET.2, TP16.TP, U1.3 (!WP!(IO2)), U1.7 (!HOLD!/!RESET!(IO3)), U1.8 (VCC), U2.2 (3V3), U3.2 (VCC)
32KHZ: R2-PINH1.1, U2.9 (IO1), U3.1 (32KHZ)
DN: D1.1 (I/O1_1), J2.A7, J2.B7
DP: D1.3 (I/O2_1), J2.A6, J2.B6
EPD_3V3: C7.1, EPD_C5.2, J1.15, J1.16, L1.2, Q2.2 (S), TP17.TP
EPD_3V3_C: Q2.1 (G), R_CL1.1, TP13.TP, U2.18 (IO20)
EPD_BUSY: J1.9, TP9.TP, U2.26 (IO3)
EPD_CS: D11.2, J1.12, R9.1, TP10.TP, U2.11 (IO10)
EPD_DC: J1.11, TP11.TP, U2.5 (IO5)
EPD_RST: J1.10, TP12.TP, U2.21 (IO23)
FLASH_CS: D10.2, R8.1, U1.1 (!CS), U2.12 (IO11)
GDR: J1.2, Q3.1 (G), R4.2
I2C_PW: C1.1, C2.1, R1_PINH.2, R2-PINH.2, SENSOR2.2 (CSB), SENSOR2.6 (VDDIO), SENSOR2.8 (VDD), U2.17 (IO19)
INT_RTC: R1_PINH1.1, TP15.TP, U2.8 (IO0), U3.3 (SQW/!INT)
IO/BOOT: BOOT_BUTTON.3, BOOT_BUTTON.4, C6.1, R_BOOT.1, U2.15 (IO9)
IO/CHANGE: C10.1, CHANGE_BUTTON.4, R_CHANGE.1, U2.23 (IO15)
MISO: D6.2, J4.P7 (DAT0), R5.1, TP6.TP, U1.2 (DO(IO1)), U2.27 (IO2)
MOSI: D9.2, J1.14, J4.P3 (CMD), R6.1, TP7.TP, U1.5 (DI(IO0)), U2.7 (IO7)
unnamed: J2.A5, J2.A8, R2-USB1.2
unnamed: J2.B5, R2-USB.1
unnamed: C1_BAT1.1, D2.1 (CATHODE), IC4.1 (VIN), IC4.3 (CE), Q1.2 (S)
unnamed: CHG_LED.C, R1_BAT.1
unnamed: C4.1, D3.2 (A), D4.1 (K)
unnamed: MCP73831.1 (STAT), R1_BAT.2
unnamed: MCP73831.5 (PROG), R2_BAT.2
unnamed: EPD_C1.2, J1.4
unnamed: EPD_C2.2, J1.5
unnamed: C_DELAY.1, IC1.5 (CT)
unnamed: D7.1 (CATHODE), R_CAPACITOR.1
unnamed: EPD_C12.2, J1.24
unnamed: EPD_C10.2, J1.22
unnamed: EPD_C9.1, EPD_C11.2, J1.21, J1.23
unnamed: EPD_C8.2, J1.20
unnamed: EPD_C7.2, J1.19
unnamed: EPD_C6.2, J1.18
PREVGH: D5.1 (K)
RESE: J1.3, Q3.2 (S), R3.2
RESE': R2.2, R3.1, SJ1.2
RESET: C5.1, IC1.1 (VOUT), RESET_BUTTON.3, RESET_BUTTON.4, R_RESET.1, U2.3 (EN)
RTC_RST: U2.16 (IO18), U3.4 (!RST)
RX: TP2.TP, U2.24 (RXD0/GPIO17)
SCK: D8.2, J1.13, J4.P5 (CLK), R7.1, TP8.TP, U1.6 (CLK), U2.6 (IO6)
SCL: J3.4, R2-PINH.1, SENSOR2.4 (SCK), U2.20 (IO22), U3.16 (SCL), U4.7 (SCL)
SDA: J3.3, R1_PINH.1, SENSOR2.3 (SDI), U2.19 (IO21), U3.15 (SDA), U4.8 (SDA)
SRC: C4.2, D5.2 (A), L1.1, Q3.3 (D)
SS_SD: D12.2, J4.P2 (CD/DAT3), R10.1, U2.4 (IO4)
TX: TP1.TP, U2.25 (TXD0/GPIO16)
USB_D+: D1.4 (I/O2_2), U2.14 (IO13)
USB_D-: D1.6 (I/O1_2), U2.13 (IO12)
VBAT: C2_BAT.1, D2.2 (ANODE), MCP73831.3 (VBAT), Q1.1 (G), R1_PWRUSB.2, TP3.TP, U4.2 (CELL), U4.3 (VDD)
VBUS: C1_BAT.1, C4_USB.1, C5_USB.1, CHG_LED.A, D1.2 (GND), MCP73831.4 (VIN), PFMF.050.1.2, TP14.TP
VRTC: C8.1, C10_SUPERCAP.2, R_CAPACITOR.2, U3.14 (VBAT)
VUSB: J2.A4, J2.A9, J2.B4, J2.B9, PFMF.050.1.1

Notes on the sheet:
USB C connector & ESD protection
LDO Voltage Regulator
SD Card
Display Type Selector
E-Paper Drive Circuit
Li-Po Battery Charging Controller
ESP32 C6
E-Paper Display Header
EPD Power
Environmental Sensor BME688
Voltage Supervisor + Reset & Boot / IO Button
Battery Charge Level
RTC Module DS3231SN
Test Pads
Qwiic / Stemma QT
SPI ESD Protection Lines
External NOR Flash 64MB
eBook Reader
drawn by: Diana Marcu

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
Board: 2 copper layers, 103 parts (0 on the bottom side), 55 nets, no tracks yet.

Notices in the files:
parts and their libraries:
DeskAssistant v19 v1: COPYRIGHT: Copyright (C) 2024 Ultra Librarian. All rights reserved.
